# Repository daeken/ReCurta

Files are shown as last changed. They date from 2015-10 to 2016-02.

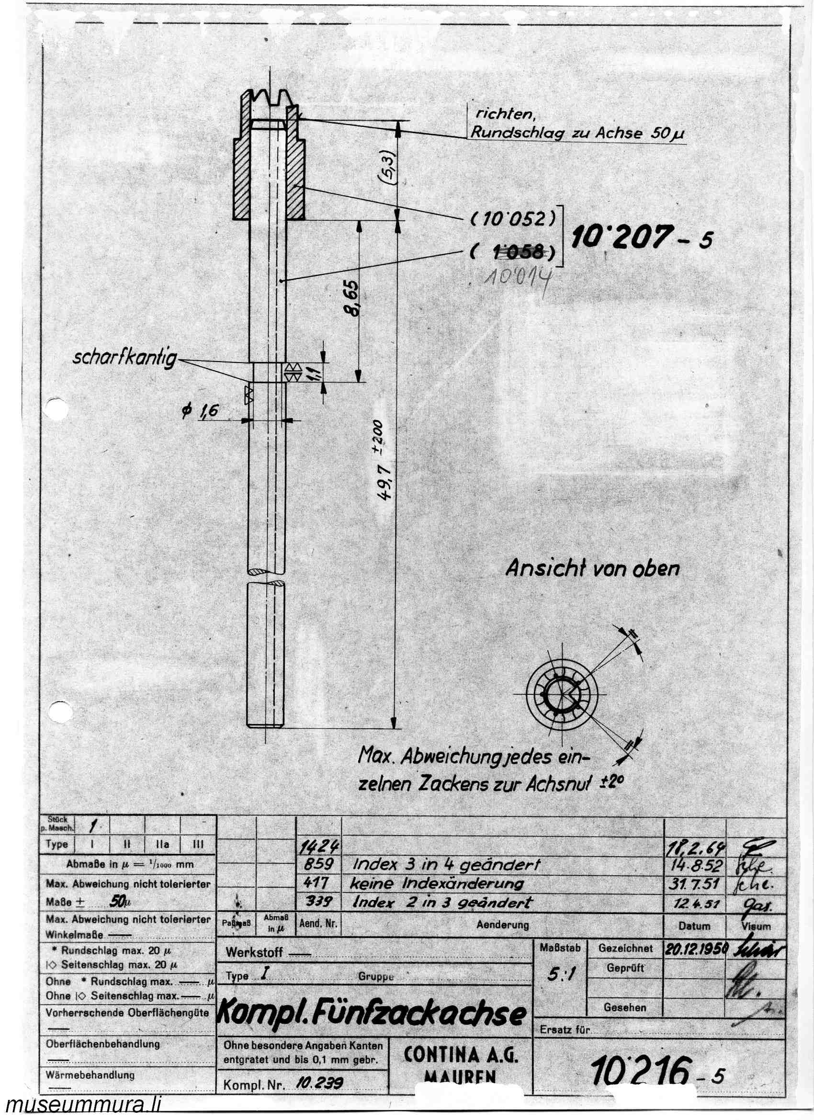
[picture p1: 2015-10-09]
app/curta_jpegs/assembly/Curta_1_10216.jpg

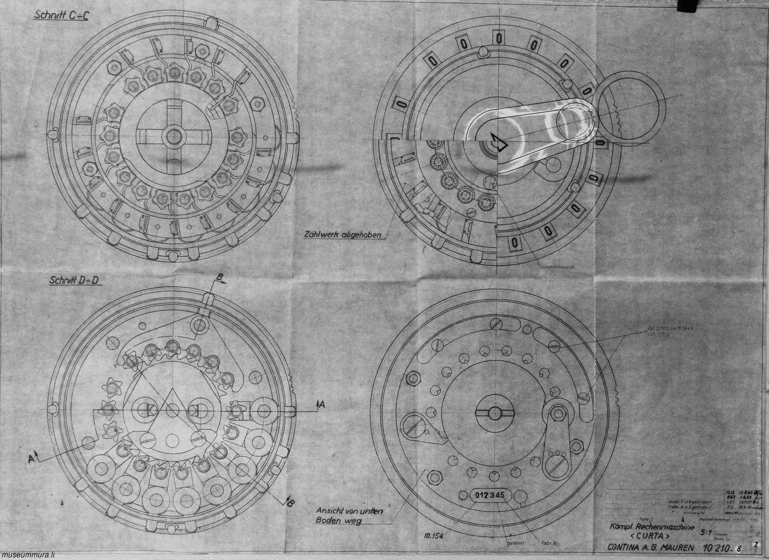
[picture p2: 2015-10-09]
app/curta_jpegs/assembly/Curta_1_10210_Z2.jpg

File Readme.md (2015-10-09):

Welcome to the ReCurta project!  Our goal is to translate the original Curta Type I engineering diagrams into English, redraw them using CAD software, and then use those diagrams to build the first Curta calculator since 1972.

Everything produced as part of this project is being released into the public domain.  Everyone should be able to inspect, visualize, or even build their own Curta calculator; it shouldn't be fated to forever be an expensive relic on eBay.

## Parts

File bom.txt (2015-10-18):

|| [[[10001]]] || Step drum body || 1 || M ||
|| [[[10002]]] || Housing top || 1 || M ||
|| [[[10003]]] || Main shaft || 1 || L ||
|| [[[10004]]] || Spider spring || 1 || C ||
|| [[[10005]]] || Ten carry lever for results || 10 || C ||
|| [[[10006]]] || Ten carry lever for turns || 5 || C ||
|| [[[10007]]] || Ten carry lever spring || 15 || Spring wind ||
|| [[[10008]]] || Numeral dial axles || 17 || L ||
|| [[[10009]]] || Tens bell body || 1 || L ||
|| [[[10010]]] || Step drum positioning tongue || 1 || C ||
|| [[[10011]]] || Upper main casting || 1 || M ||
|| [[[10012]]] || Crank handle || 1 || L ||
|| [[[10014]]] || Transmission shaft || 17 || L ||
|| [[[10015]]] || Shouldered screw || 1 || L ||
|| [[[10016]]] || Carriage shift positioning pin || 1 || L ||
|| [[[10018]]] || Ten carry lever bearing block || 15 || M ||
|| [[[10019]]] || Full carry pin || 7 || L ||
|| [[[10020]]] || Guide sleeve for transmission gears (aka 410345) || 1 || Lathe + Compression ||
|| [[[10021]]] || Half carry pin || 8 || M ||
|| [[[10022]]] || Crank handle pin || 1 || L ||
|| [[[10023]]] || Reversing lever spring || 1 || Buy ||
|| [[[10024]]] || Clearing plate plunger || 1 || L ||
|| [[[10025]]] || Main bearing sleeve body || 1 || L ||
|| [[[10026]]] || Carriage holding nut || 1 || L ||
|| [[[10027]]] || Carriage shift positioning pin || 1 || L ||
|| [[[10028]]] || Baseplate || 1 || M ||
|| [[[10029]]] || Number dial || 8 || L ||
|| [[[10030]]] || Clearing plate body || 1 || M ||
|| [[[10031]]] || Retaining ring || 1 || C ||
|| [[[10032]]] || Guide sleeve for transmission gears (aka 410346) || 1 || Lathe + Compression ||
|| [[[10033]]] || Flat spring || 1 || C ||
|| [[[10034]]] || Clearing Lever || 1 || M ||
|| [[[10035]]] || Retaining bushing for carriage pressure spring || 1 || L ||
|| [[[10036]]] || C-clip || 1 || M ||
|| [[[2118]]] || Retaining screw || 2 || L ||
|| [[[10038]]] || Count gear I (aka 410347) || 20 || C ||
|| [[[10039]]] || Clearing lever position plunger || 1 || L ||
|| [[[10040]]] || Carriage casting || 1 || M ||
|| [[[100402]]] || !IGNORE Carriage casting support IGNORE! || 1 ||  ||
|| [[[10041]]] || Ferrule (aka 410348) || 2 || L ||
|| [[[10042]]] || Transmission gear spacer (aka 410349) || 2 || L ||
|| [[[10043]]] || Numeral dial I || 4 || L ||
|| [[[10045]]] || Numeral dial II || 13 || L ||
|| [[[10046]]] || Decimal marker || 7 || L ||
|| [[[10047]]] || Decimal marker spring || 7 || Buy ||
|| [[[10048]]] || Cylindrical screws || 2 || L ||
|| [[[10049]]] || Lock gear (aka 410350) || 17 || C ||
|| [[[10050]]] || Carriage pressure spring || 1 || Buy ||
|| [[[10051]]] || Transmission gear spacer (aka 410351) || 15 || L ||
|| [[[10052]]] || Transmission gear || 17 || M ||
|| [[[10053]]] || Count gear II (aka 410352) || 15 || C ||
|| [[[10054]]] || Ferrule (aka 410353) || 15 || L ||
|| [[[10055]]] || Guide sleeve for transmission gears (aka 410354) || 15 || Lathe + Compression ||
|| [[[10056]]] || Guide sleeve for transmission gears || 1 || Lathe + Compression ||
|| [[[10057]]] || Setting knob || 8 || M ||
|| [[[10058]]] || NRP (Non-Return Pawl) spring || 1 || Buy ||
|| [[[10059]]] || NRP shouldered screw || 1 || L ||
|| [[[10061]]] || Setting Shaft || 8 || L ||
|| [[[10062]]] || Lower housing ring || 1 || L ||
|| [[[10064]]] || Support column || 3 || L ||
|| [[[10065]]] || Reversing lever axle || 1 || L ||
|| [[[10066]]] || Reversing handle || 1 || M ||
|| [[[10067]]] || Reversing plate || 1 || M ||
|| [[[10068]]] || Step drum positioning cam || 1 || L ||
|| [[[10069]]] || Taper pin for step drum || 1 || L ||
|| [[[10070]]] || Step drum positioning spring || 1 || M ||
|| [[[10071]]] || Locking ring || 1 || C ||
|| [[[10072]]] || Tens bell locking pin || 1 || L ||
|| [[[10073]]] || Setting knob spring || 8 || Buy ||
|| [[[10074]]] || Countersunk screws || 3 || L ||
|| [[[10075]]] || Guiding screw || 8 || L ||
|| [[[10076]]] || Drum plate 10 tooth || 1 || C ||
|| [[[10077]]] || Lower main casting || 1 || M ||
|| [[[10078]]] || Drum plate 1 tooth || 5 || C ||
|| [[[10079]]] || Drum plate 9 tooth || 2 || C ||
|| [[[10080]]] || Drum plate 2 tooth || 6 || C ||
|| [[[10081]]] || Drum plate 8 tooth || 2 || C ||
|| [[[10082]]] || Drum plate 3 tooth || 6 || C ||
|| [[[10083]]] || Drum plate 7 tooth || 2 || C ||
|| [[[10084]]] || Drum plate 4 tooth || 6 || C ||
|| [[[10085]]] || Collar || 1 || L ||
|| [[[10086]]] || Clearing plate spring || 1 || Buy ||
|| [[[10087]]] || Drum plate 6 tooth || 2 || C ||
|| [[[10088]]] || Carriage ring || 1 || L ||
|| [[[10089]]] || Carriage cage || 1 || M ||
|| [[[10090]]] || Drum plate 5 tooth || 5 || C ||
|| [[[10091]]] || Drum plate 1 tooth || 6 || C ||
|| [[[10093]]] || Clearing lever rivet || 1 || L ||
|| [[[10094]]] || Rivet washer || 1 || M ||
|| [[[10095]]] || Spring housing || 1 || L ||
|| [[[10096]]] || Drum plate 9 tooth || 1 || C ||
|| [[[10097]]] || Circlip for count gear || 9 || Cut or buy ||
|| [[[10098]]] || Small distance spring || 1 || M ||
|| [[[10099]]] || Clearing plate distance ring || 1 || M ||
|| [[[10100]]] || Turns counter carry increment || 1 || M ||
|| [[[10101]]] || Result counter carry increment || 1 || M ||
|| [[[10102]]] || Tens bell insert ring || 1 || M ||
|| [[[10103]]] || Tens bell insert ring || 2 || M ||
|| [[[10104]]] || Turns counter carry reset ring || 1 || M ||
|| [[[10105]]] || Turns counter lock ring || 1 || M ||
|| [[[10106]]] || Result counter carry reset ring || 1 || M ||
|| [[[10107]]] || Result counter lock ring || 1 || M ||
|| [[[10109]]] || Trunnion screw || 1 || L ||
|| [[[10110]]] || Transmission gear spacer (aka 410356) || 1 || L ||
|| [[[10111]]] || Zero positioning disc || 1 || L ||
|| [[[10112]]] || Zero positioning roller || 1 || L ||
|| [[[10113]]] || Non Return Pawl || 1 || M ||
|| [[[10114]]] || Zero positioning lever || 1 || M ||
|| [[[10115]]] || Zero positioning lever spring || 1 || Buy ||
|| [[[10116]]] || Screw for zero positioning lever || 1 || L ||
|| [[[2037]]] || Screw for zero positioning lever (looks to be for type II) || 1 || L ||
|| [[[10118]]] || Disc spring clip || 1 || Bend ||
|| [[[10119]]] || End plate || 1 || M ||
|| [[[10120]]] || Tens bell support plate || 1 || C ||
|| [[[10121]]] || Non Return Pawl bushing || 1 || L ||
|| [[[2074]]] || Nut || 2 || Buy ||
|| [[[10124]]] || Container tightening ring || 1 || Buy ||
|| [[[10125]]] || Barrel of zero positioning lever || 1 || L ||
|| [[[10126]]] || Decorative cover for top of capsule || 1 || M ||
|| [[[10129]]] || Carriage pressure ring || 1 || C ||
|| [[[10130]]] || Rubber cushion, large || 1 || Buy ||
|| [[[10131]]] || Rubber cushion, small || 1 || Buy ||
|| [[[10133]]] || C-clip || 1 || C ||
|| [[[10134]]] || Carriage turn stop pin || 1 || L ||
|| [[[10135]]] || Setting shaft bearing pin || 8 || L ||
|| [[[10136]]] || Setting shaft plates || 2 || C ||
|| [[[10137]]] || Retaining bushing, large || 1 || L ||
|| [[[10138]]] || Retaining bushing, small || 1 || L ||
|| [[[10140]]] || Guide sleeve for transmission gears (aka 410359) || 16 || Lathe + Compression ||
|| [[[10141]]] || Ferrule (aka 410360) || 17 || L ||
|| [[[10142]]] || Curved tooth racks || 2 || C ||
|| [[[10143]]] || Spacer for clearing plate || 1 || C ||
|| [[[10145]]] || Steel ball || 1 || Buy ||
|| [[[10147]]] || Main bearing sleeve bushing || 1 || L ||
|| [[[10148]]] || Cylindrical pin || 1 || L ||
|| [[[10149]]] || Cylindrical pin || 2 || L ||
|| [[[10150]]] || Cylindrical pin || 1 || L ||
|| [[[10152]]] || Split washer || 1 || Buy ||
|| [[[10153]]] || Shim washer || 1 || M ||
|| [[[10154]]] || Internal serial number plate || 1 || M ||
|| [[[10156]]] || Decorative plate for capsule || 1 || M ||
|| [[[10158]]] || Baseplate design || 1 || M ||
|| [[[10160]]] || Baseplate design II (Alternate drawing?) || 1 || M ||
|| [[[10161]]] || Retaining nut (Unused?) || 1 || L ||
|| [[[10162]]] || Washer || 1 || Buy ||
|| [[[410367]]] || Taper pin || 1 || L ||
|| [[[10203]]] || Number dial I || 4 ||  ||
|| [[[10204]]] || Number dial IIa || 7 ||  ||
|| [[[10205]]] || Number dial IIb || 4 ||  ||
|| [[[10206]]] || Tens bell || 1 ||  ||
|| [[[10207]]] || Transmission axle with gear || 1 ||  ||
|| [[[10208]]] || Transmission shaft || 12 ||  ||
|| [[[10209]]] || Transmission shaft || 1 ||  ||
|| [[[10210]]] || Main assembly || 1 ||  ||
|| [[[10211]]] || Reversing handle assembly || 1 ||  ||
|| [[[10212]]] || Complete setting shaft || 1 ||  ||
|| [[[10213]]] || Step drum || 1 ||  ||
|| [[[10214]]] || Main shaft || 1 ||  ||
|| [[[10215]]] || Lower housing || 1 ||  ||
|| [[[10216]]] || Transmission shaft || 1 ||  ||
|| [[[10218]]] || Triple count gear assembly || 1 ||  ||
|| [[[10219]]] || Double count gear assembly || 1 ||  ||
|| [[[10220]]] || Tens gear/locking assembly || 15 ||  ||
|| [[[10221]]] || Non-carry locking assembly || 1 ||  ||
|| [[[10222]]] || Non-carry locking assembly (Long) || 1 ||  ||
|| [[[10223]]] || Main shaft || 1 ||  ||
|| [[[10224]]] || Non return pawl assembly || 1 ||  ||
|| [[[10225]]] || Zero positioner lever || 1 ||  ||
|| [[[10226]]] || Carriage casting || 1 ||  ||
|| [[[10227]]] || Upper main body with tens bell || 1 ||  ||
|| [[[10228]]] || Capsule assembly || 1 ||  ||
|| [[[10229]]] || Main bearing sleeve || 1 ||  ||
|| [[[10230]]] || Single count gear assembly || 15 ||  ||
|| [[[10231]]] || Lower main casting assembly || 1 ||  ||
|| [[[10232]]] || Assembly step I || 1 ||  ||
|| [[[10233]]] || Assembly step II || 1 ||  ||
|| [[[10234]]] || Assembly step III || 1 ||  ||
|| [[[10236]]] || Transmission shaft, IV || 12 ||  ||
|| [[[10237]]] || Transmission shaft, I || 1 ||  ||
|| [[[10238]]] || Transmission shaft, II || 3 ||  ||
|| [[[10239]]] || Transmission shaft, III || 1 ||  ||
|| [[[10240]]] || Setting handle complete assembly || 8 ||  ||
|| [[[10241]]] || Reversing switch complete assembly || 1 ||  ||
|| [[[10242]]] || Plastic crank || 1 ||  ||
|| [[[10243]]] || Carriage assembly step I || 1 ||  ||
|| [[[10244]]] || Clearing plate || 1 ||  ||
|| [[[10245]]] || Crank handle || 1 ||  ||
|| [[[10246]]] || Zero positioner || 1 ||  ||
|| [[[10247]]] || Clearing plate with pressed segments || 1 ||  ||
|| [[[10248]]] || Upper main body with pins || 1 ||  ||
|| [[[10249]]] || Baseplate assembly || 1 ||  ||
|| [[[10250]]] || Setting handle with guide screw || 8 ||  ||

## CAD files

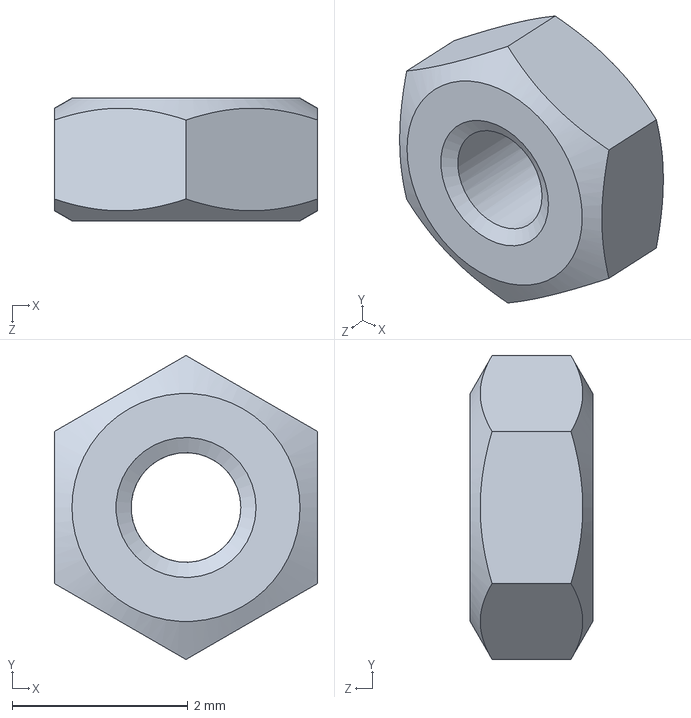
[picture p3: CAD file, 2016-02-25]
Solidworks Drawings/2074.sldprt
3.00 x 3.46 x 1.40 mm

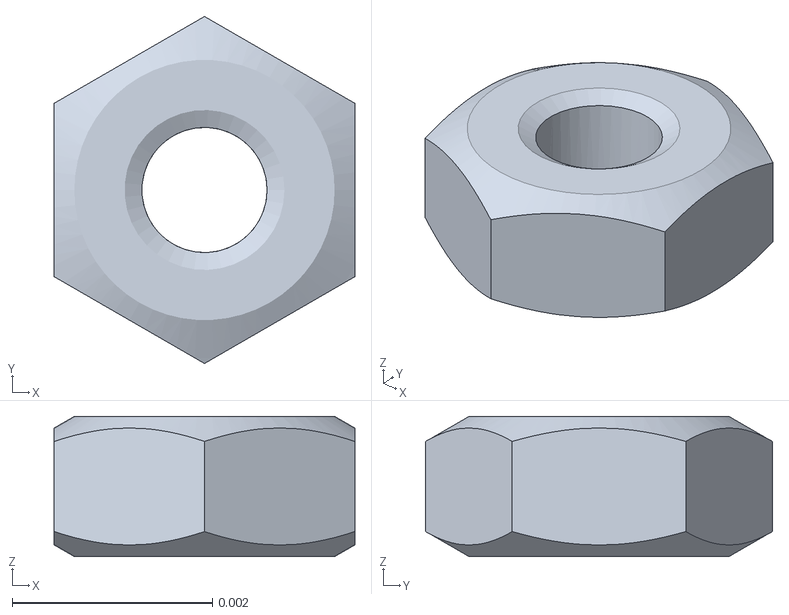
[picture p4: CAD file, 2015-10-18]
STL Models/2074.stl
0.003 x 0.00346 x 0.0014

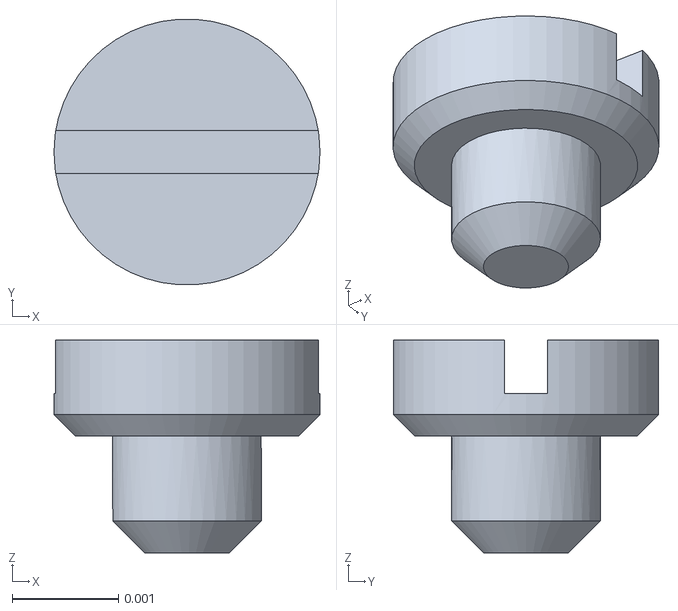
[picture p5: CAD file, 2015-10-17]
STL Models/2118.stl
0.0025 x 0.0025 x 0.002

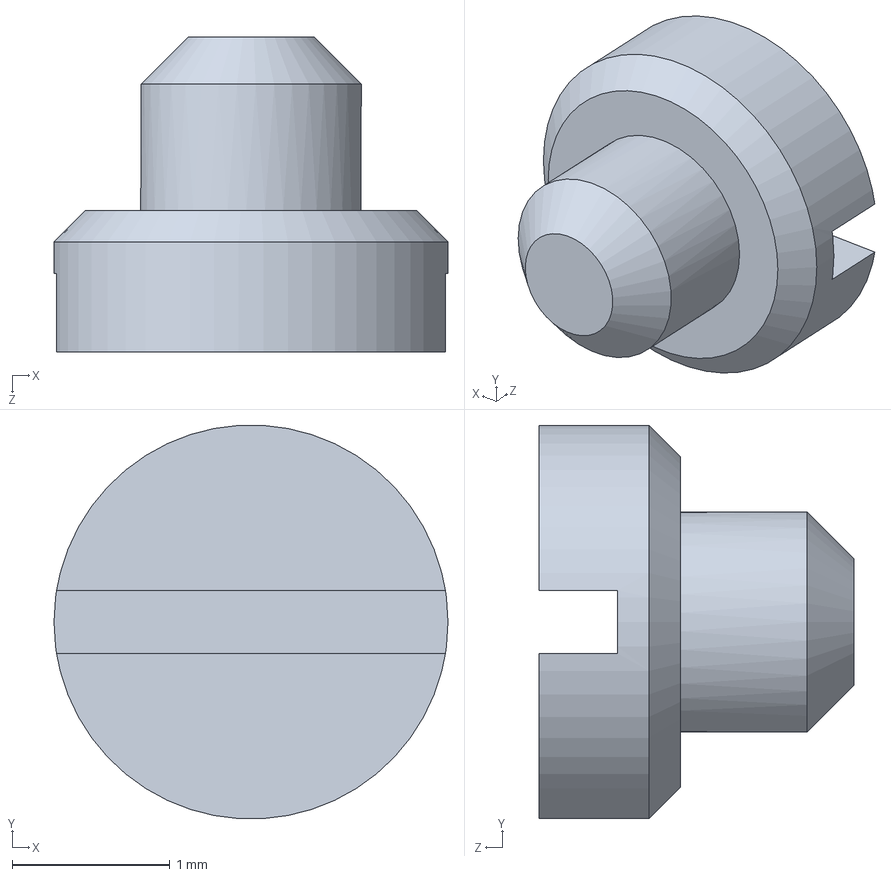
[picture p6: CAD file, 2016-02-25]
Solidworks Drawings/2118.sldprt
2.50 x 2.50 x 2.00 mm

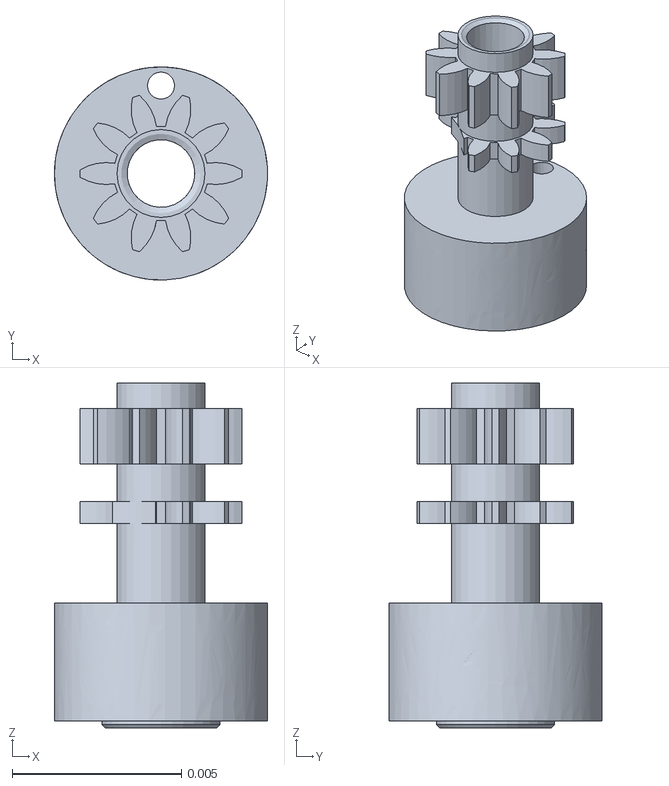
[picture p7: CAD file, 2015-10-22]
STL Models/10043.stl
0.0063 x 0.0063 x 0.0102

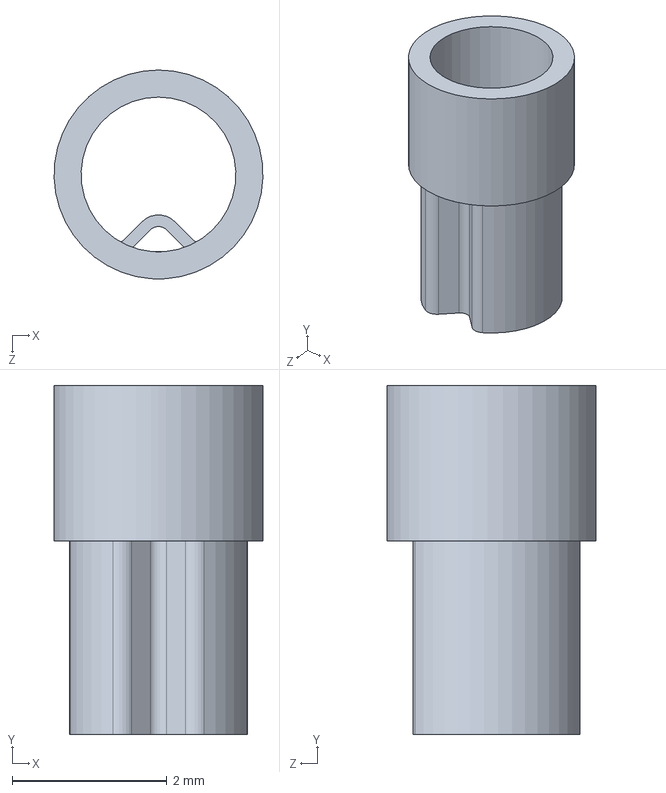
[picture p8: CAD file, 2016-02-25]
Solidworks Drawings/10140.sldprt
2.70 x 4.51 x 2.70 mm

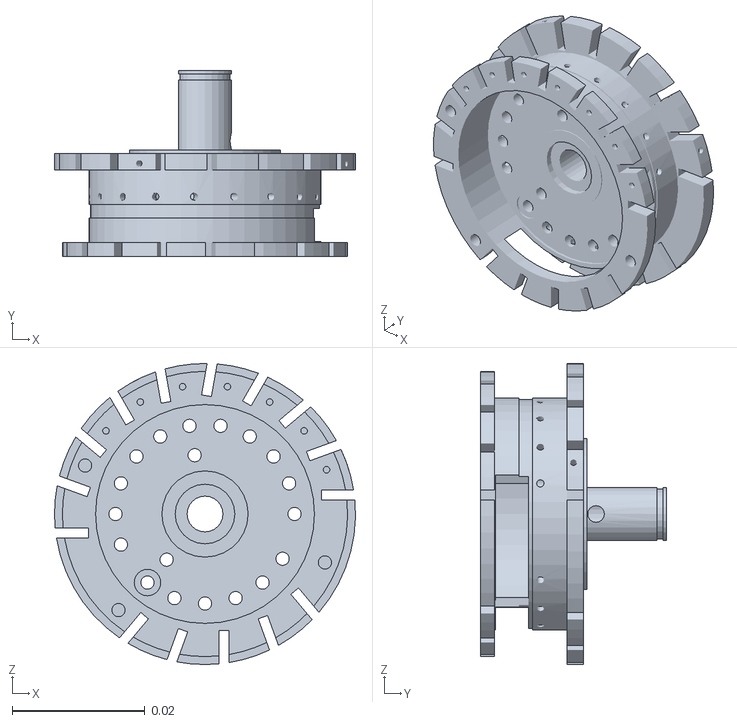
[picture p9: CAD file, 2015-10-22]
STL Models/10011.stl
0.0454 x 0.028 x 0.0454

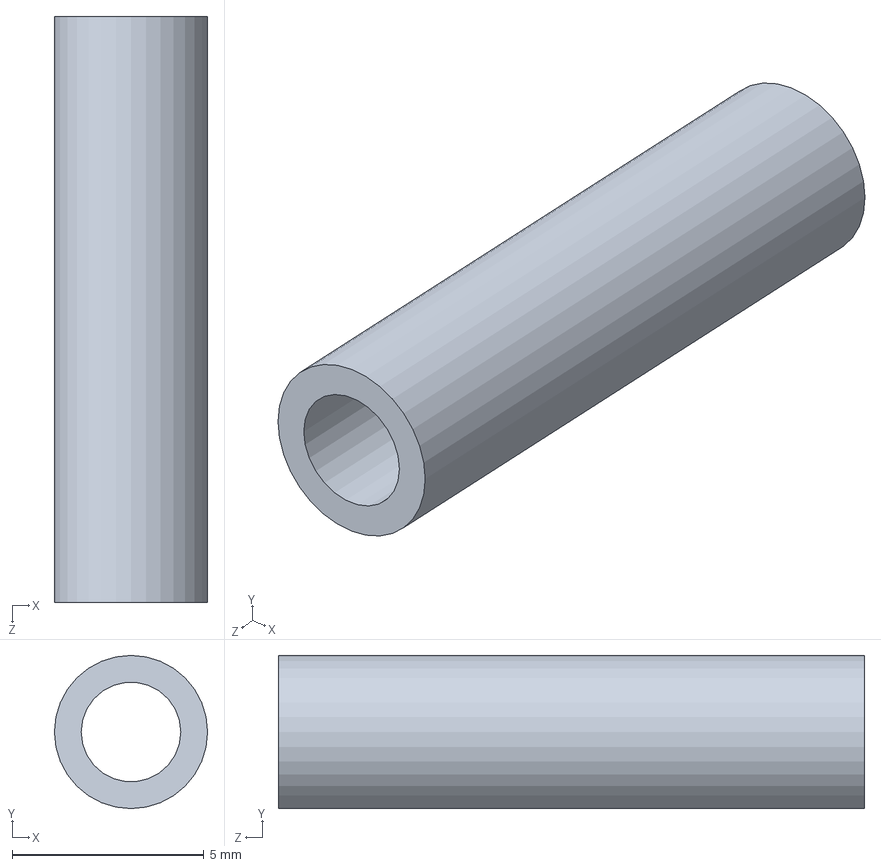
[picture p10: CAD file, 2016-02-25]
Solidworks Drawings/10137.sldprt
4.00 x 4.00 x 15.3 mm

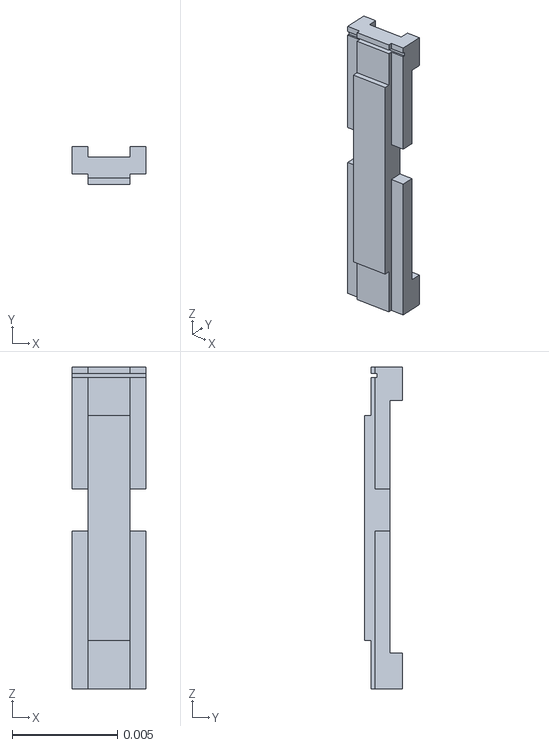
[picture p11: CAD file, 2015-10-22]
STL Models/10018.stl
0.0035 x 0.0018 x 0.0153

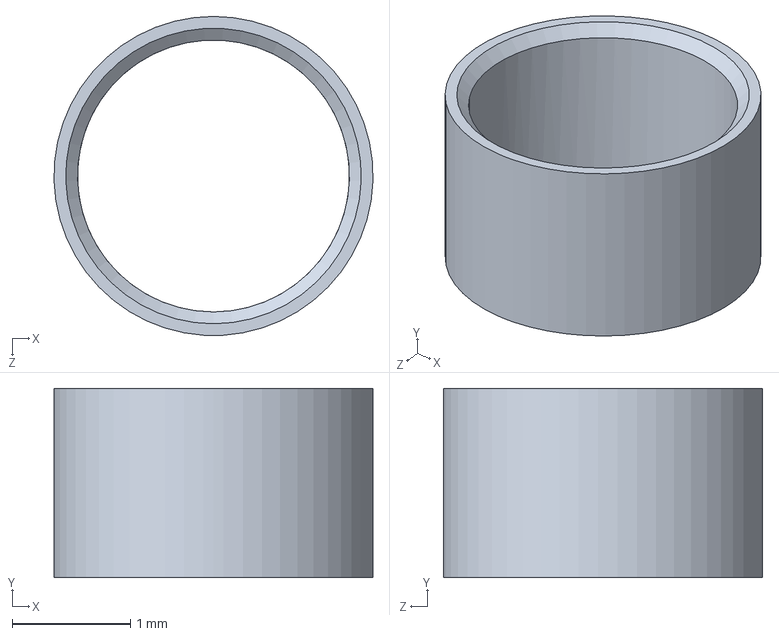
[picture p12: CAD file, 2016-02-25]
Solidworks Drawings/10141.sldprt
2.70 x 1.60 x 2.70 mm

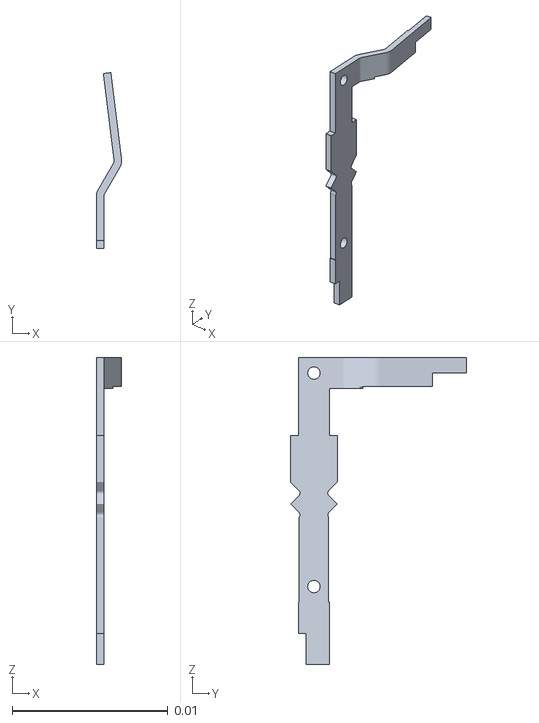
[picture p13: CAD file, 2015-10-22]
STL Models/10005.stl
0.00163 x 0.0113 x 0.0197

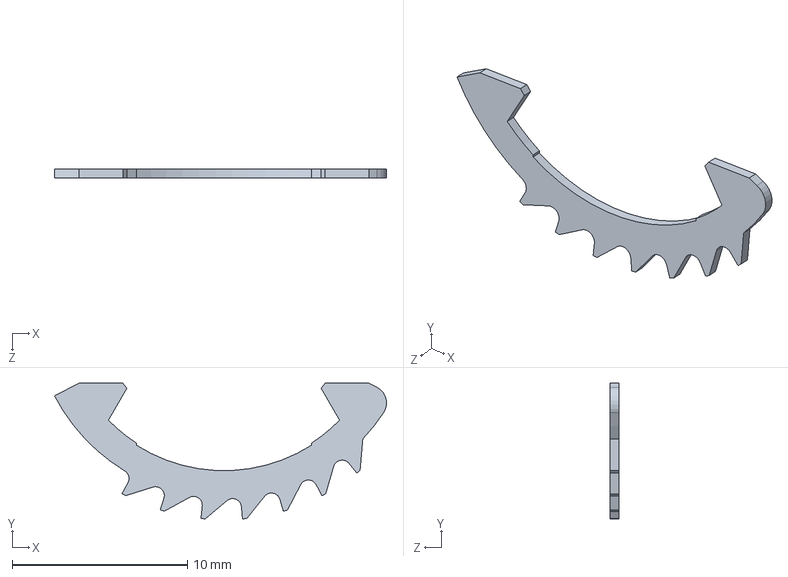
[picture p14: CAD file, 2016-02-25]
Solidworks Drawings/10083.sldprt
18.9 x 7.75 x 0.5 mm

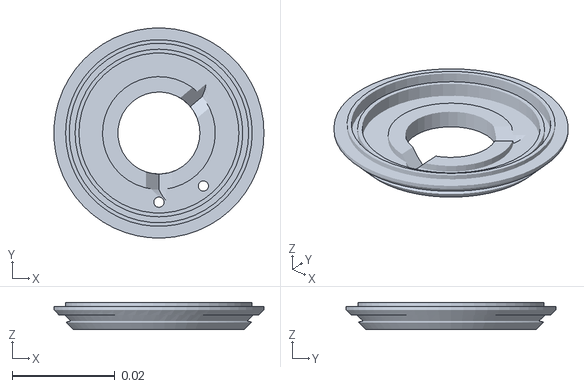
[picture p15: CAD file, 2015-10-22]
STL Models/10030.stl
0.041 x 0.041 x 0.0053

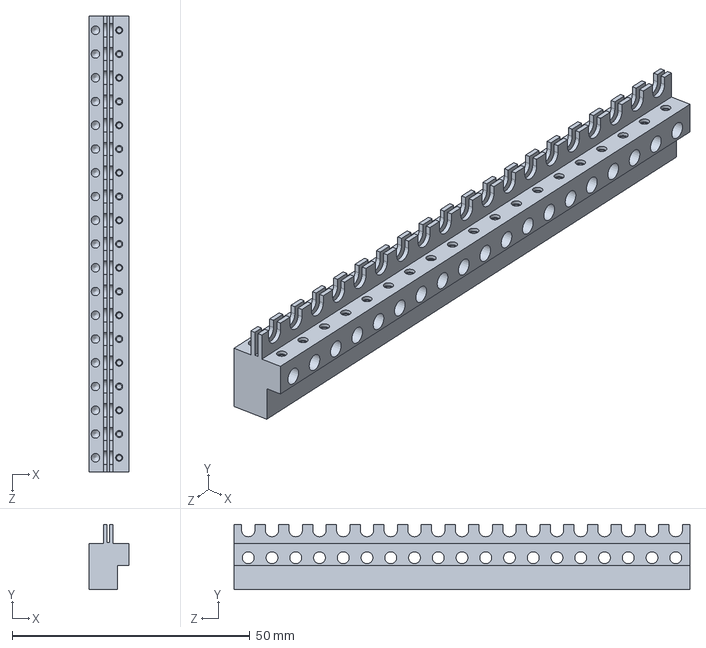
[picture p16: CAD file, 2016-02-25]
Solidworks Drawings/10057.sldprt
8.50 x 13.7 x 96.0 mm

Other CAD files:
STL Models/10101.stl
Solidworks Drawings/10112.sldprt
STL Models/10006.stl
Solidworks Drawings/10002.sldprt
STL Models/10001.stl
STL Models/10003.stl
STL Models/10004.stl
STL Models/10007.stl
STL Models/10008.stl
STL Models/10009.stl
STL Models/10010.stl
STL Models/10012.stl
STL Models/10014.stl
STL Models/10015.stl
STL Models/10019.stl
STL Models/10020.stl
STL Models/10021.stl
STL Models/10022.stl
STL Models/10023.stl
STL Models/10024.stl
STL Models/10025.stl
STL Models/10026.stl
STL Models/10028.stl
STL Models/10029.stl
STL Models/10031.stl
STL Models/10032.stl
STL Models/10033.stl
STL Models/10034.stl
STL Models/10035.stl
STL Models/10036.stl
STL Models/10038.stl
STL Models/10039.stl
STL Models/10040.stl
STL Models/10041.stl
STL Models/10042.stl
STL Models/10045.stl
STL Models/10046.stl
STL Models/10047.stl
STL Models/10048.stl
STL Models/10049.stl
STL Models/10050.stl
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

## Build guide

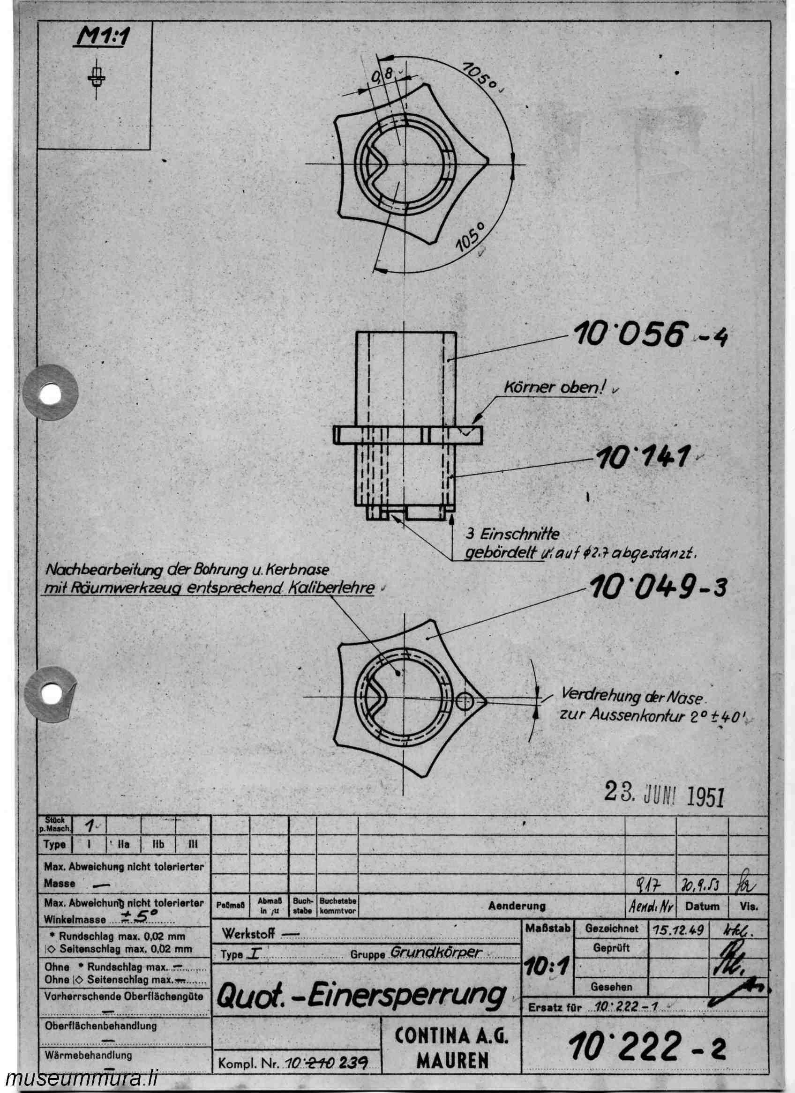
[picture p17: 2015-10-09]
app/curta_jpegs/assembly/Curta_1_10222.jpg

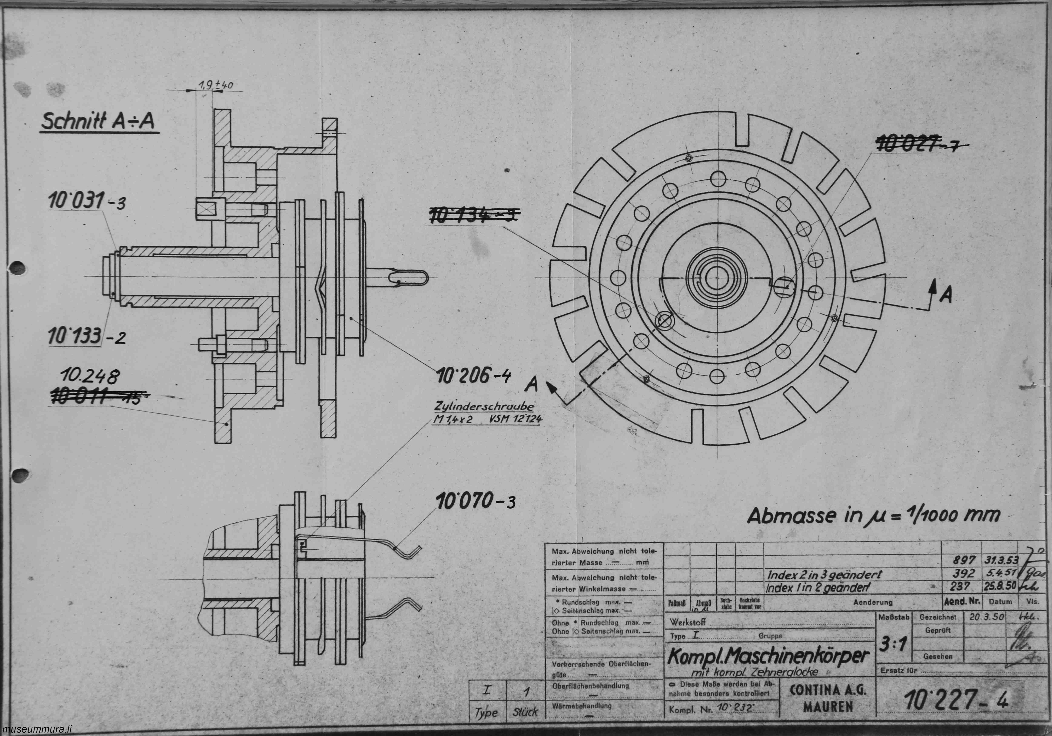
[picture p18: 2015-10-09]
app/curta_jpegs/assembly/Curta_1_10227.jpg

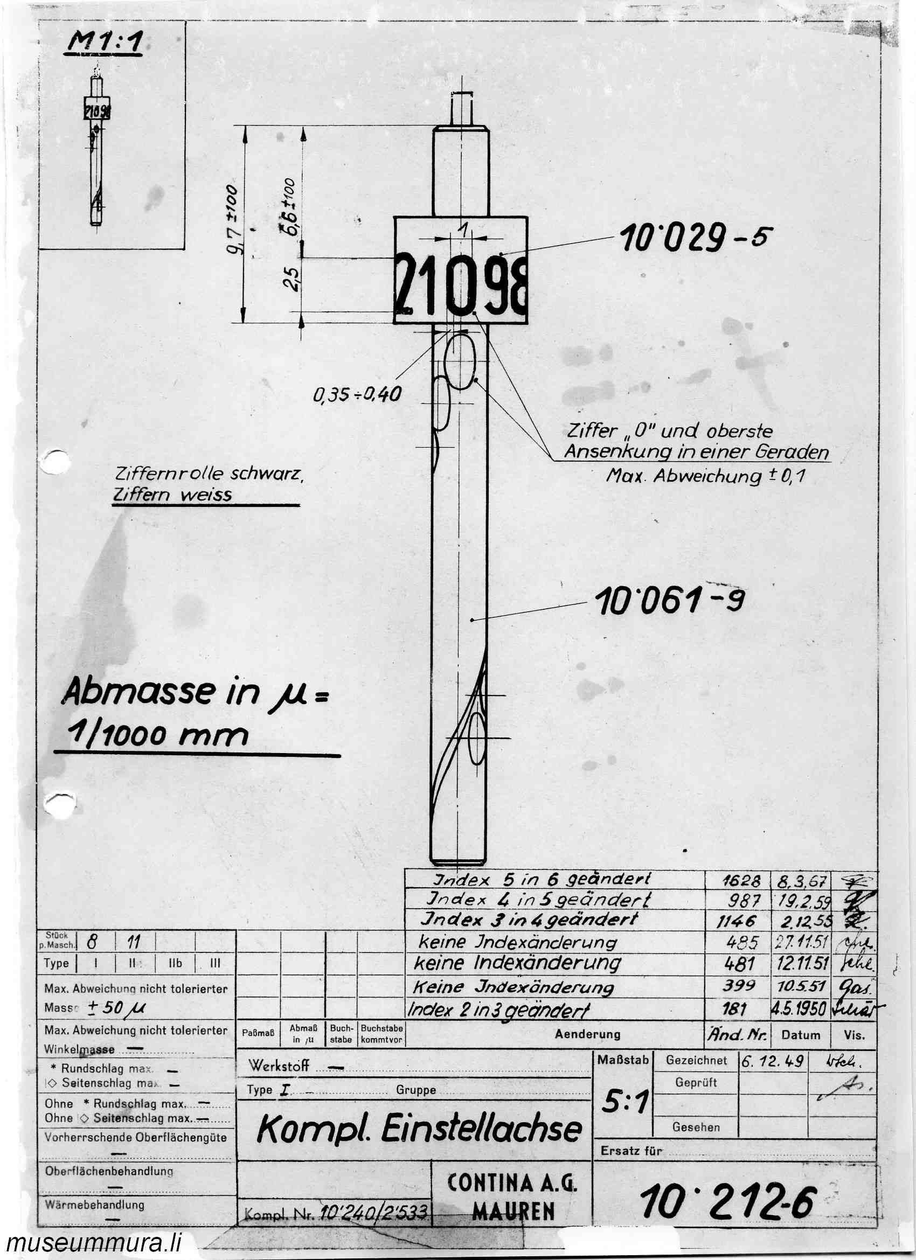
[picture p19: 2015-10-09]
app/curta_jpegs/assembly/Curta_1_10212.jpg

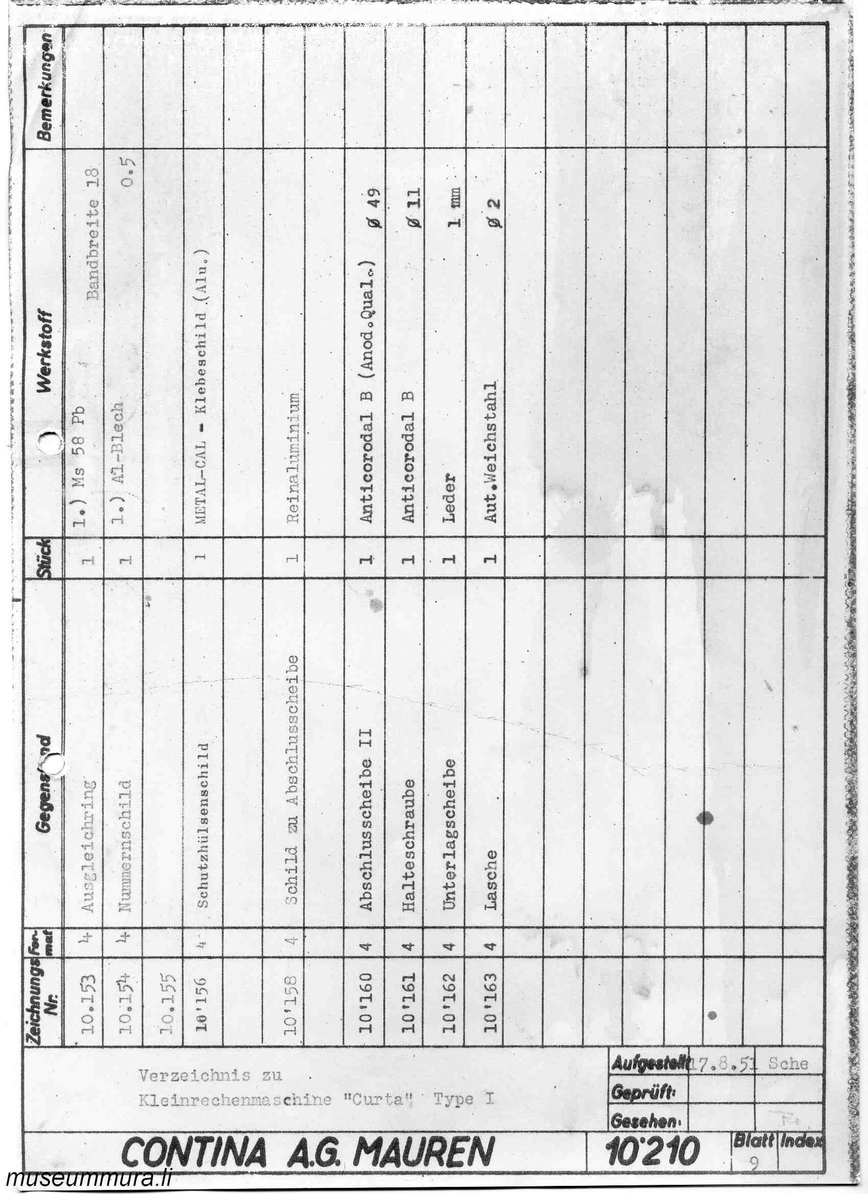
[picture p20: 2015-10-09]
app/curta_jpegs/assembly/Curta_1_10210_9.jpg

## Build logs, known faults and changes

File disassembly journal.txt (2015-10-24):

Top already off, case off.

Setting shaft plate 1 removed -- 10136
clockwise-most setting shaft bearing and shaft removed -- 10135, 3.38mm length (real 3.377mm).  marked #1
second bearing removed.  3.41mm length, 3.404mm real. marked #2
third removed.  3.44mm intended length, 3.404mm real. marked #3
fourth removed.  3.47mm intended length, 3.405mm real. marked #4
second shaft plate removed
fifth bearing removed.  3.50mm intended length, 3.414mm real. marked #5
sixth bearing removed.  3.53mm intended length, 3.407mm real. marked #6
seventh bearing removed.  3.56mm intended length, 3.386mm real! marked #7.  2.288mm diameter (2.3mm expected)
eighth bearing removed.  3.59mm intended length, 3.403mm real. marked #8.

looking at the curta with the shaft (where the handle would be) pointing away and the reversing lever to the left, i'm taking out the first setting position carry assembly.
using purple screwdriver, removed screw (M1.4x5, VSM 12124).  lifted assembly straight out.
first removed carry lever (10005) from bearing block (10018), then slipped spring (10007) off bearing block.
second carry assembly removed with same procedure.
NOTE: lever fits into bearing block with short end of lever barely sticking out!

while holding carry assembly, hold it with the flat face of lever (and spring ends) pointing up.  lift lever out of place, then push tines of spring down to release it securely.  third through tenth removed and disassembled using this procedure, safely.

the same procedure was followed for the tens carry assemblies for turns.  these use lever 10006 -- NOT 10005.

removed hex nut from reversing lever assembly.  pushed shaft down until slotted section of shaft appeared, then pulled the assembly straight out, through the slot in the lower casting.  removed lower bearing from shaft (unknown part number.  15.282mm long, 4mm OD, 2.42mm ID), and removed upper bearing from shaft (unknown part number.  5.011mm long, 4mm OD, 2.4mm ID). all parts placed into labeled container

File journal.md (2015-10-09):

10/08/15
=======

Decided to start keeping a development journal, to properly document this project once it's completed.

Status
------

- All drawings for the Type I are converted from the museummura.li sources
- Each part has been named in English and cross-referenced with the others
	- Every part referenced from each manufacturing diagram is indexed
- Out of 146 part diagrams, all but 38 are fully translated; those remaining 38 have 57 individual German phrases that need to be translated
	- These have all been automatically rewritten into English
- All of this is published on Github

Next Steps
----------

- Complete translations of all of the diagrams
	- Perform final review
- Add translated diagrams to the wiki
- Find and hire CAD designers to begin translation of diagrams to modern formats
- Determine all of the different manufacturing processes that need to be used
- Calculate approximate prices for replicas

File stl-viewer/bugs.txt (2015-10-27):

10021 missing flat face
10039 missing cap
10059 missing half its top
10068 missing top
10072 missing top
10074 missing part of top
10075 missing part of top
10076 missing part of one tooth
10078 empty?
10080 empty?
10082 empty?
10083 empty?
10084 empty?

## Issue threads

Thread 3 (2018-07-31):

Assembly

neilpanchal, 2018-07-31:
Is there a final assembly file, preferably in Solidworks? I've watched and looked at several documents including the service manual, but there is no way I can figure out how to assemble the parts in this repository into a final Solidworks assembly.

tswaugh, 2018-07-31:
There's an assembly video out there for the 3x scale 3D printed Curta: https://www.youtube.com/watch?v=zh2Z11miQ0w

neilpanchal, 2018-08-02:
@tswaugh No, I didn't mean physical assembly. I meant assembly of CAD parts. In Solidworks, you can build an assembly (.sldasm) from individual parts (.sldprt). It is just not putting parts together in CAD, but putting the right axial rotation, translation, angular constraints including spring tension.

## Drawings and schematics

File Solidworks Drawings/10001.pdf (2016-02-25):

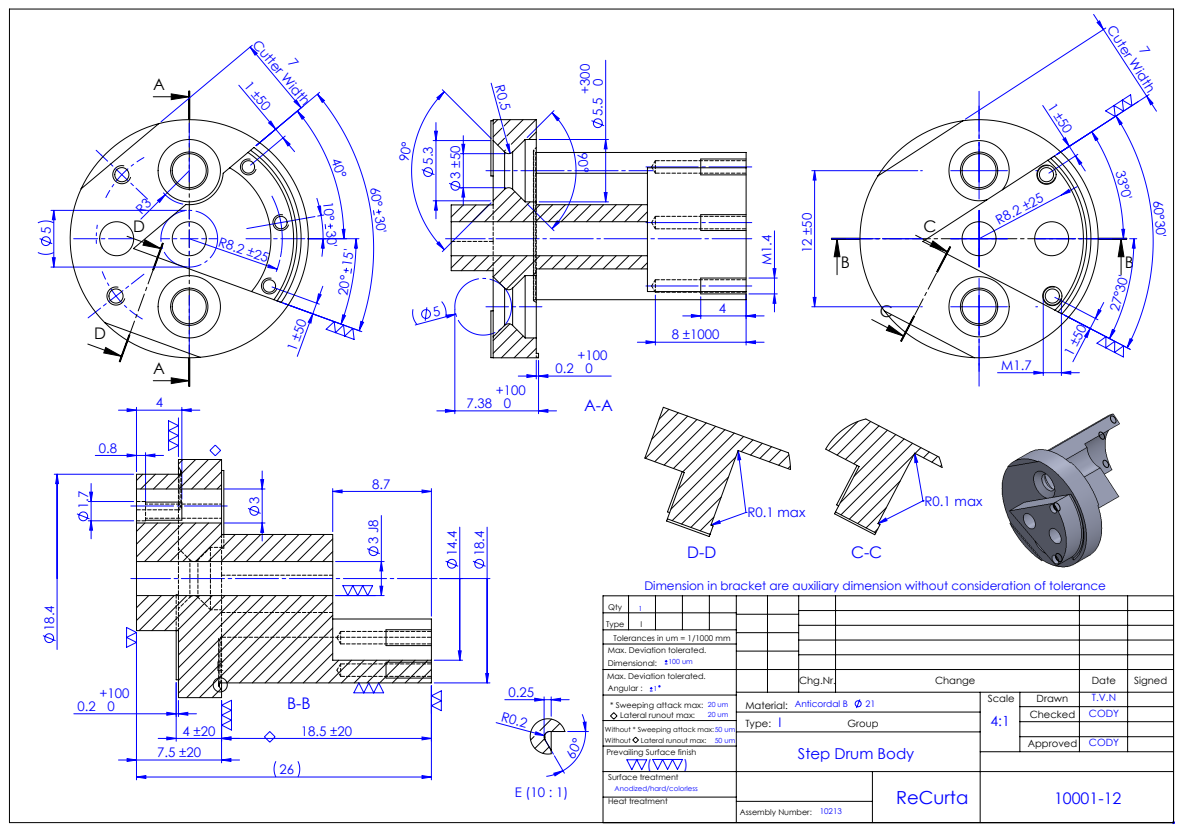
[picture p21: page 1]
Cutter Width; Cuter Width; R0.1 max; Anticordal B; Assembly Number:

Dimension in bracket are auxiliary dimension without consideration of tolerance

Qty | 1
Type | I

Tolerances in um = 1/1000 mm
Max. Deviation tolerated.
Dimensional:
Angular :
* Sweeping attack max:
Lateral runout max:
Without * Sweeping attack max:
Without Lateral runout max:
Prevailing Surface finish

Step Drum Body

Surface treatment
Anodized/hard/colorless
Heat treatment

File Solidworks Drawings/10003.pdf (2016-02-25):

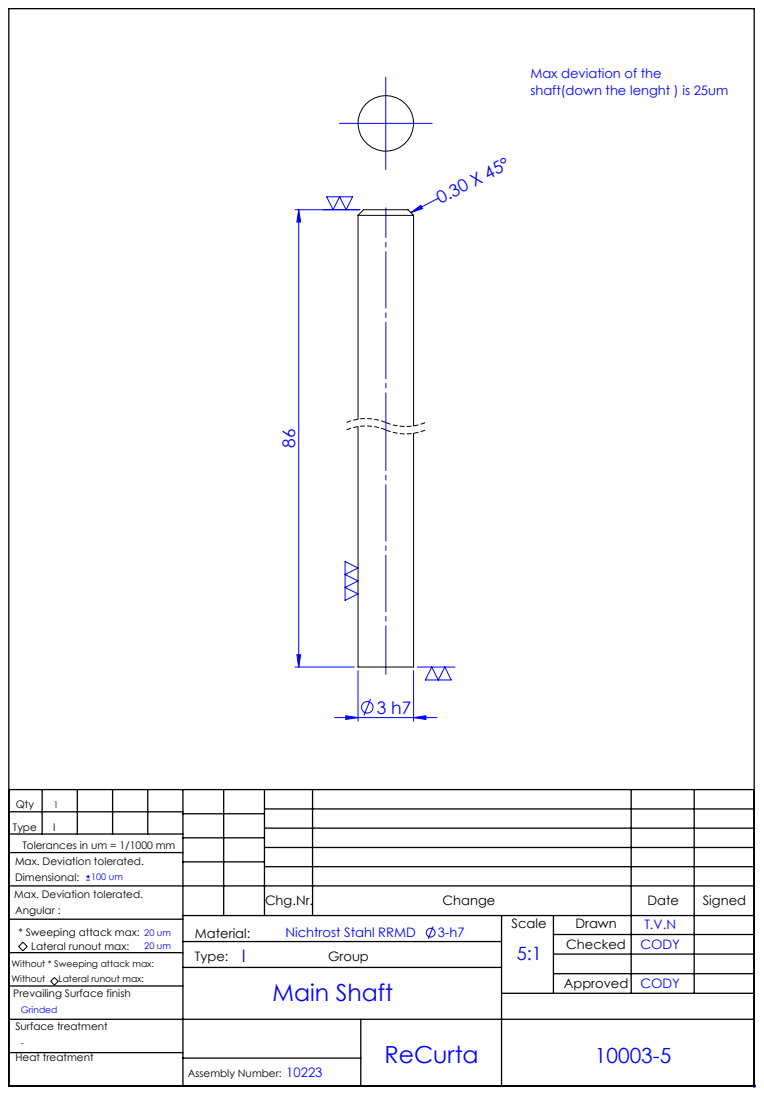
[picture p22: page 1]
Main Shaft; Assembly Number:

Max deviation of the
shaft(down the lenght ) is 25um

Qty | 1
Type | I

Tolerances in um = 1/1000 mm
Max. Deviation tolerated.
Dimensional:

Max. Deviation tolerated. Angular : | | | Chg.Nr. | Change | Date | Signed

Nichtrost Stahl RRMD 3-h7 | Scale 5:1 | Drawn Material: | T.V.N

* Sweeping attack max:
Lateral runout max:
Without * Sweeping attack max:
Without Lateral runout max:
Prevailing Surface finish
Grinded
Surface treatment
Heat treatment

Checked | CODY

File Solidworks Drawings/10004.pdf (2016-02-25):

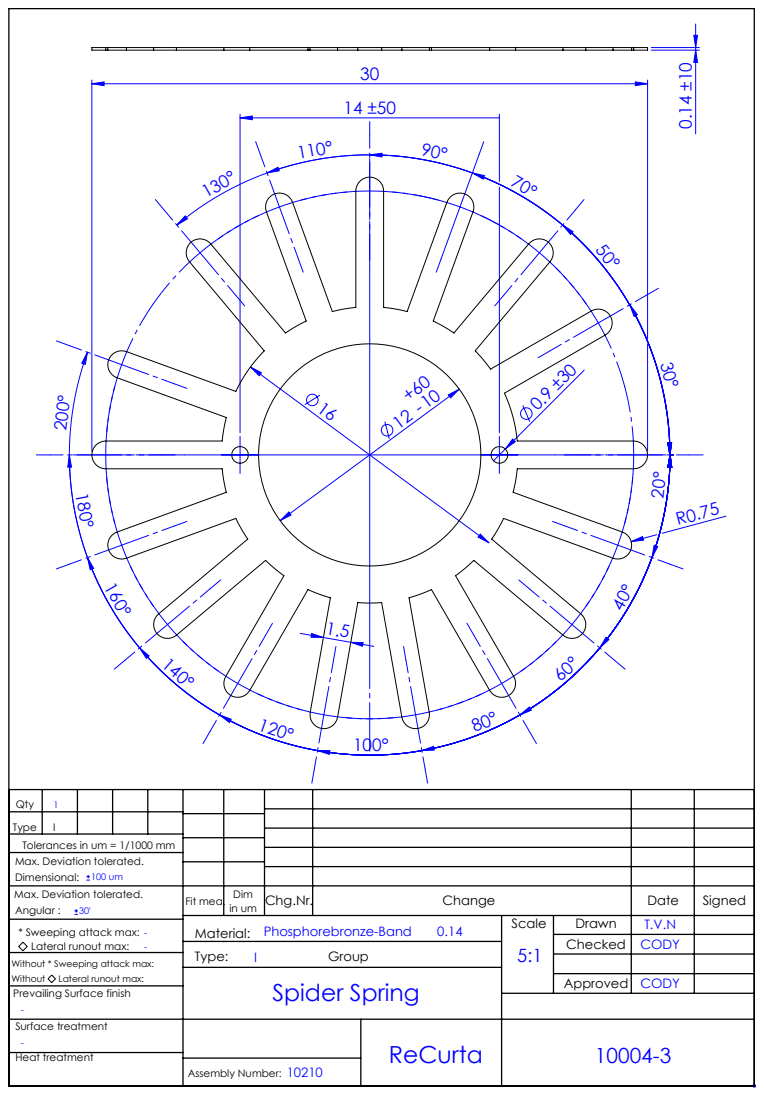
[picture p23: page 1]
Spider Spring; Assembly Number:

Qty | 1
Type | I

Tolerances in um = 1/1000 mm
Max. Deviation tolerated.
Dimensional:

Max. Deviation tolerated. Angular : 30' | Fit mea. Dim | in um | Chg.Nr. | Change | Date | Signed

Phosphorebronze-Band 0.14 | Scale 5:1 | Drawn Material: | T.V.N

* Sweeping attack max:
Lateral runout max:
Without * Sweeping attack max:
Without Lateral runout max:
Prevailing Surface finish
Surface treatment
Heat treatment

Checked | CODY

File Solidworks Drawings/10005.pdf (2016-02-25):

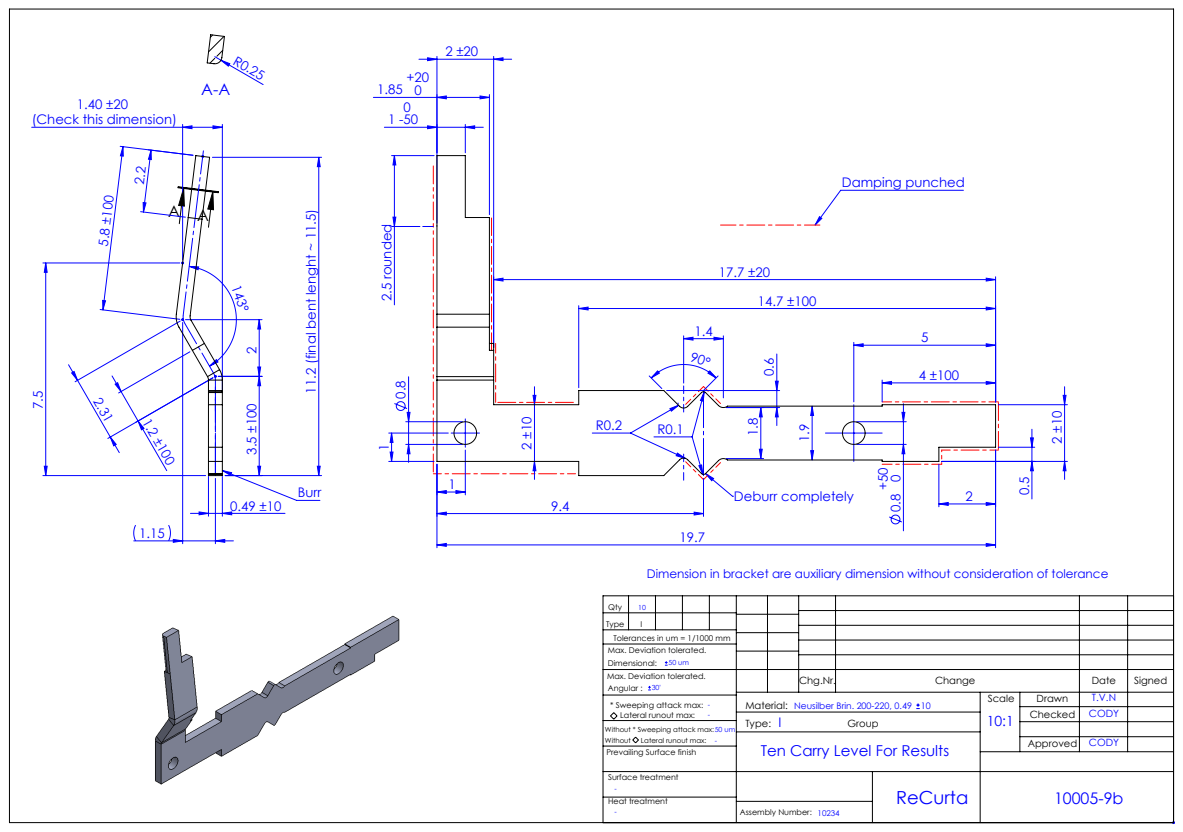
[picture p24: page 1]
2.5 rounded; Damping punched; Deburr completely; Neusilber Brin. 200-220, 0.49 10; Surface treatment; Assembly Number:

(Check this dimension)

11.2 (final bent lenght ~ 11.5)

Dimension in bracket are auxiliary dimension without consideration of tolerance

Qty | 10
Type | I

Tolerances in um = 1/1000 mm
Max. Deviation tolerated.
Dimensional:
Angular :
* Sweeping attack max:
Lateral runout max:
Without * Sweeping attack max:
Without Lateral runout max:
Prevailing Surface finish
Heat treatment

Ten Carry Level For Results

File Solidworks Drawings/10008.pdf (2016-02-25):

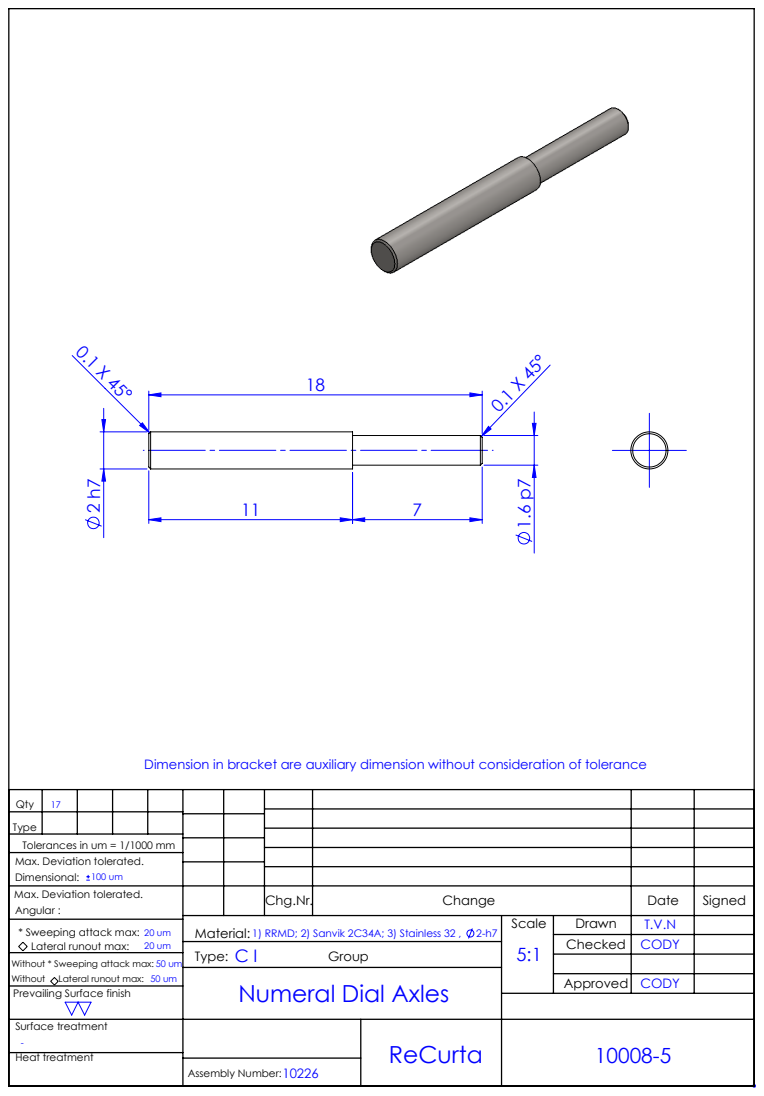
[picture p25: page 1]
Assembly Number:; Heat treatment; Surface treatment

Dimension in bracket are auxiliary dimension without consideration of tolerance

Qty | 17
Type

Tolerances in um = 1/1000 mm
Max. Deviation tolerated.
Dimensional:

Max. Deviation tolerated. Angular : | | | Chg.Nr. | Change | Date | Signed

1) RRMD; 2) Sanvik 2C34A; 3) Stainless 32 , 2-h7 | Scale 5:1 | Drawn Material: | T.V.N

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

Numeral Dial Axles

Checked | CODY

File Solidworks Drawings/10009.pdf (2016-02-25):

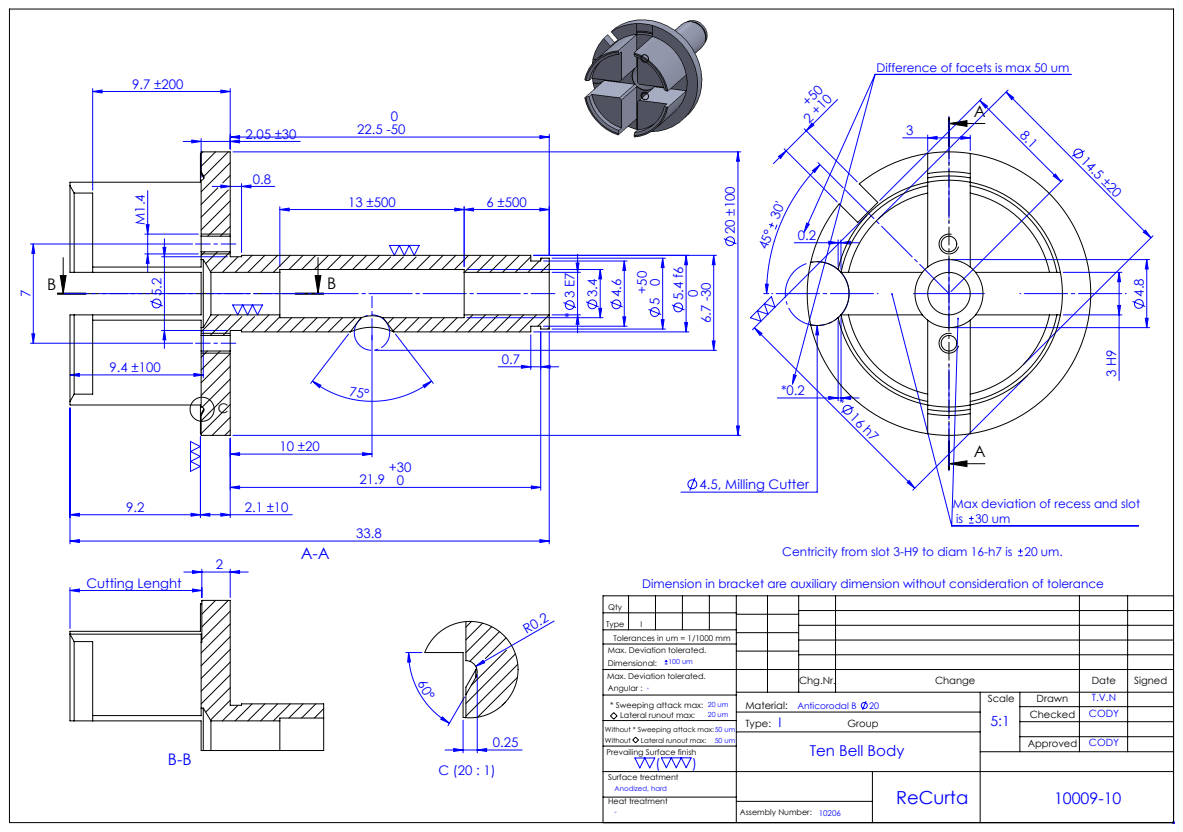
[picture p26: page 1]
4.5, Milling Cutter; Cutting Lenght; Anodized, hard; Anticorodal B 20; Centricity from slot 3-H9 to diam 16-h7 is; Surface treatment; Heat treatment; Assembly Number:

Difference of facets is max 50 um

Max deviation of recess and slot

Dimension in bracket are auxiliary dimension without consideration of tolerance

Qty
Type | I

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

Ten Bell Body

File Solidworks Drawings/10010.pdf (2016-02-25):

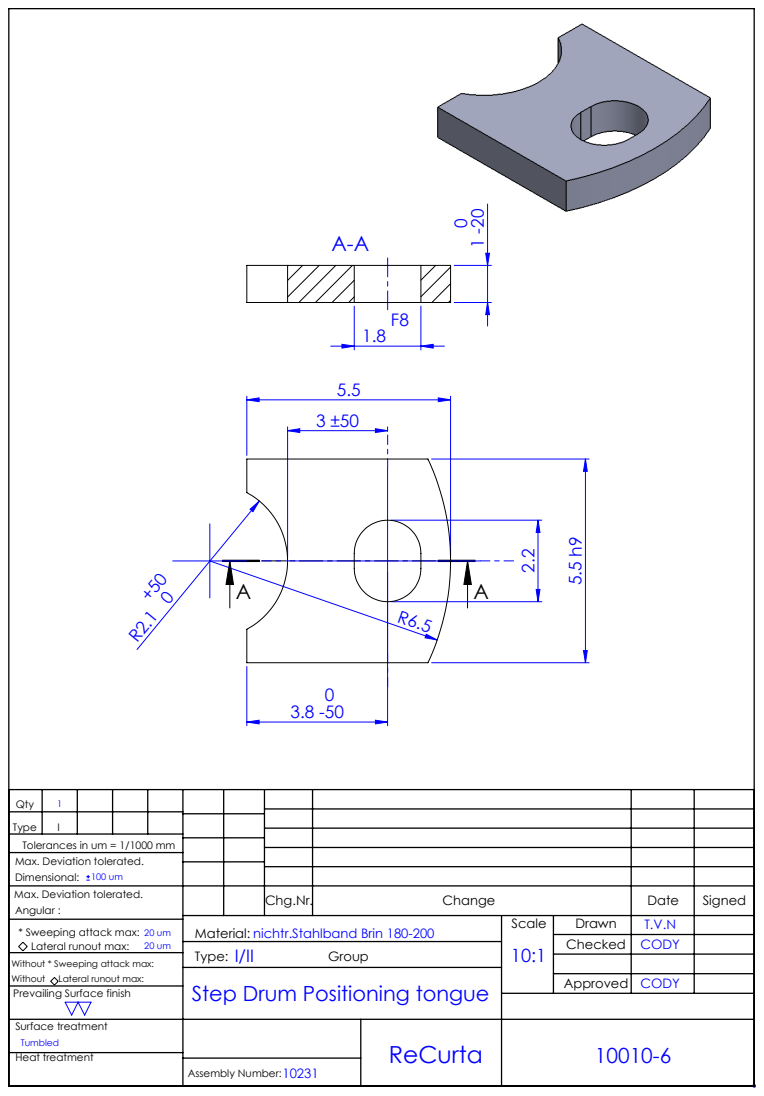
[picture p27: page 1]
Assembly Number:; Heat treatment; Surface treatment

Qty | 1
Type | I

Tolerances in um = 1/1000 mm
Max. Deviation tolerated.
Dimensional:

Max. Deviation tolerated. Angular : | | | Chg.Nr. | Change | Date | Signed

nichtr.Stahlband Brin 180-200 | Scale 10:1 | Drawn Material: | T.V.N

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

Step Drum Positioning tongue

Checked | CODY

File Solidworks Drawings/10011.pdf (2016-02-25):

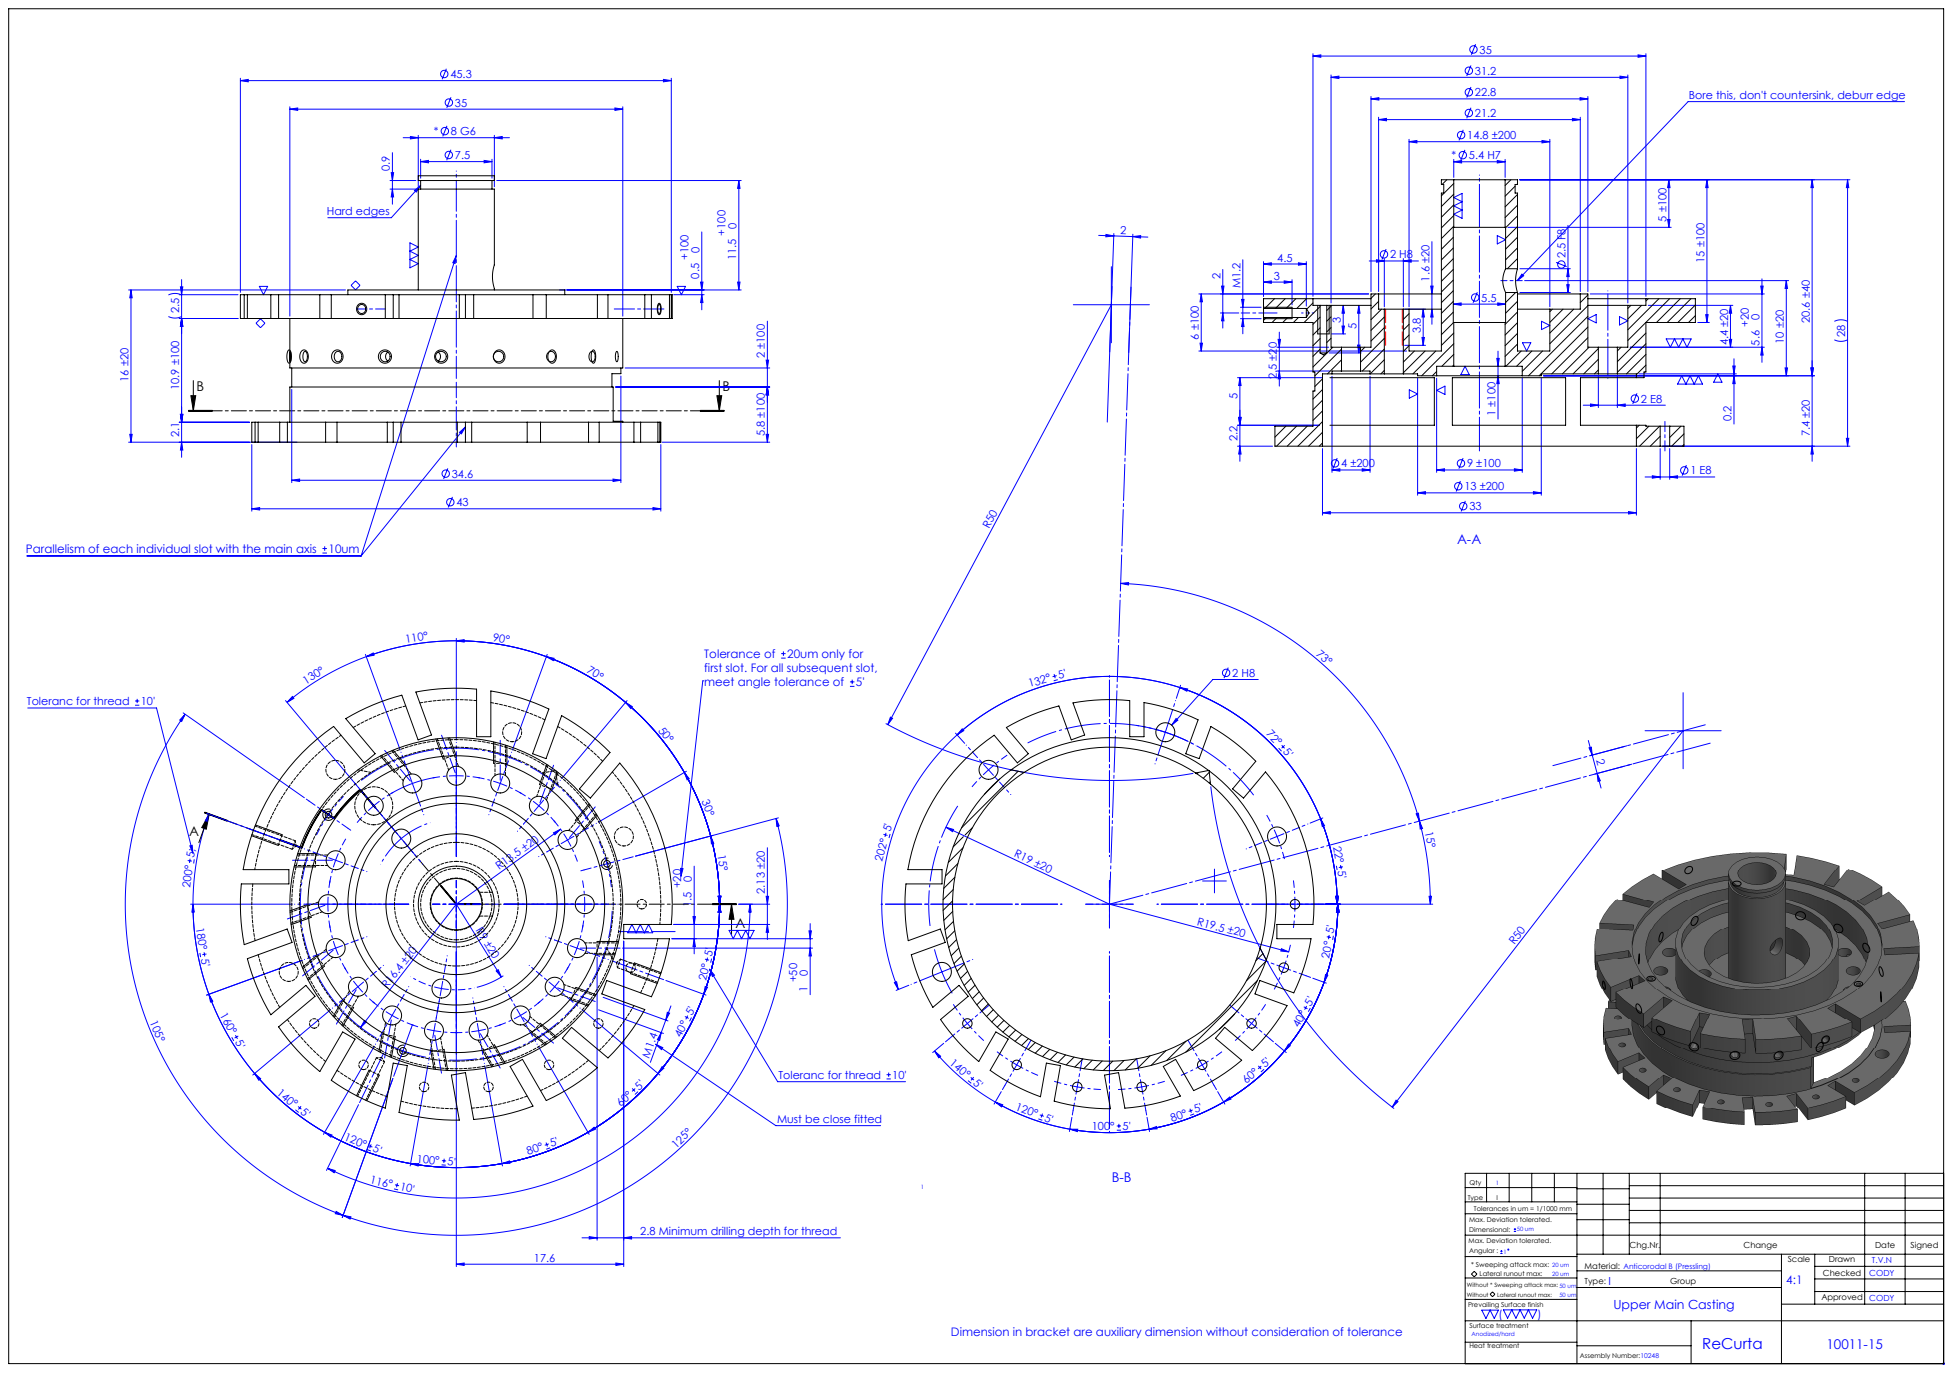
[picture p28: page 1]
Hard edges; Parallelism of each individual slot with the main axis; Toleranc for thread; Anticorodal B (Pressling); Tolerance of; 20um only for; meet angle tolerance of; Surface treatment; Heat treatment; Assembly Number:

Bore this, don't countersink, deburr edge

first slot. For all subsequent slot,

Must be close fitted

Qty | 1
Type | I

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

2.8 Minimum drilling depth for thread

Upper Main Casting

Dimension in bracket are auxiliary dimension without consideration of tolerance

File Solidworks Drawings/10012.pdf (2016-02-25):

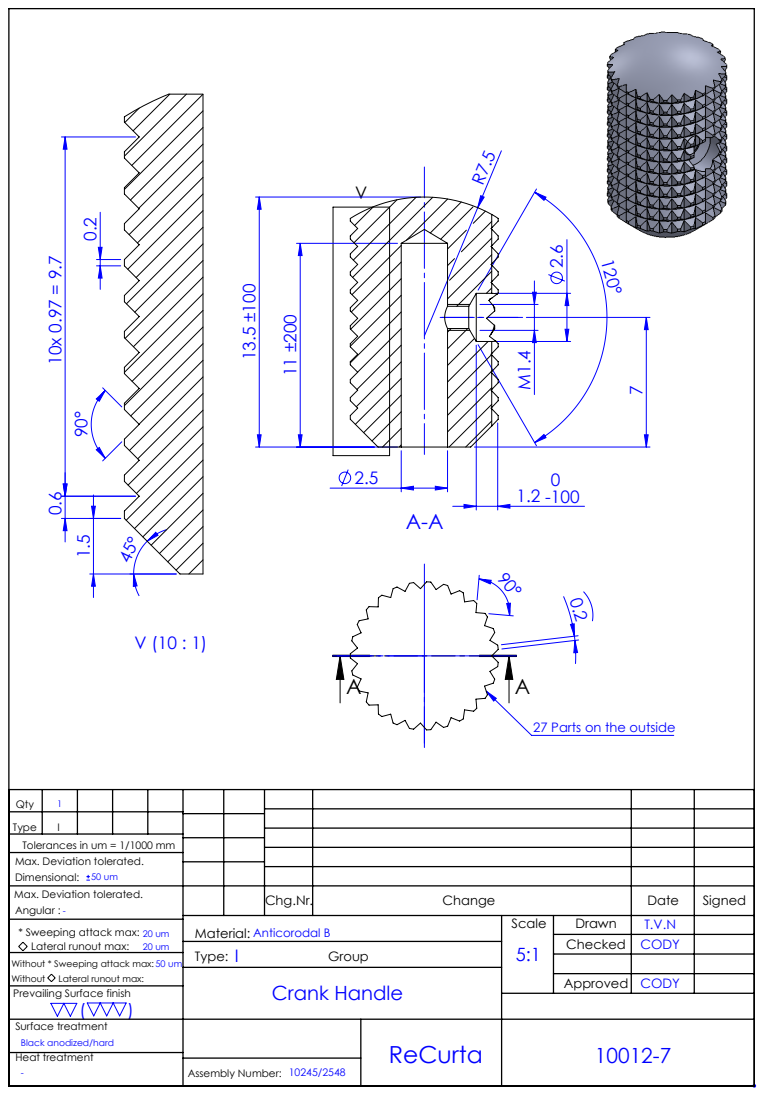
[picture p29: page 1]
Anticorodal B; Crank Handle; Scale; Drawn Material:; Assembly Number:

27 Parts on the outside

Qty | 1
Type | I

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

Surface treatment
Black anodized/hard
Heat treatment

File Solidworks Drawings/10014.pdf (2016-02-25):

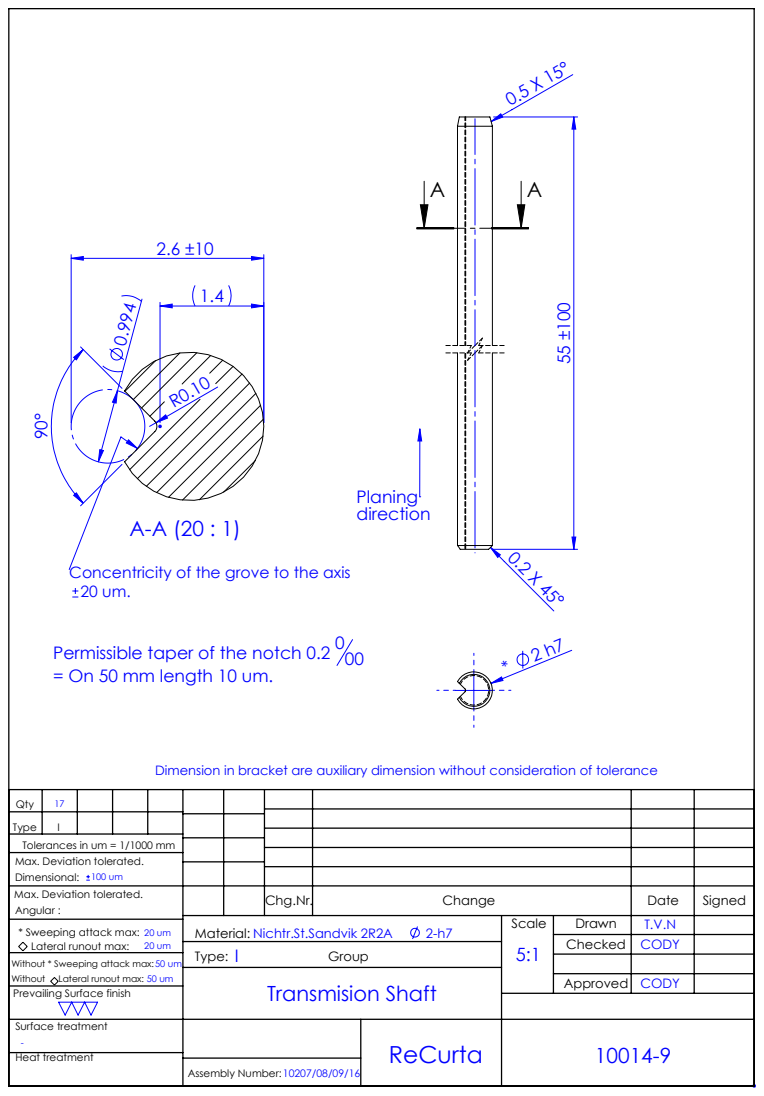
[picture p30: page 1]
Transmision Shaft; Assembly Number:; Heat treatment; Surface treatment

Concentricity of the grove to the axis

Permissible taper of the notch 0.2 0
= On 50 mm length 10 um.

Dimension in bracket are auxiliary dimension without consideration of tolerance

Qty | 17
Type | I

Tolerances in um = 1/1000 mm
Max. Deviation tolerated.
Dimensional:

Max. Deviation tolerated. Angular : | | | Chg.Nr. | Change | Date | Signed

Nichtr.St.Sandvik 2R2A 2-h7 | Scale 5:1 | Drawn Material: | T.V.N

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

Checked | CODY

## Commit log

2015-10-16 Added process field to BOM. Added initial Solidworks drawings.
    [10003-5.SLDPRT, 10004-3.SLDPRT, 10007-4.SLDDRW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]
2015-10-17 Added STL files.
    [10003.stl, 10004.stl, 10007.stl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]
2015-10-17 Added STL viewer to wiki builder.
2015-10-17 Cleaned up STL refs in wiki. Fixed offsets.
2015-10-17 Added more process details to BOM. Added part page region.
2015-10-17 Fixed more BOM entries.
2015-10-18 Swapped process for reversing plate. Added three new STLs.
    [10088-4a.stl, 10089-9.stl, 2074.stl]
2015-10-18 Fixed STL filenames.
    [10088.stl, 10089.stl]
2015-10-18 Updated 10089 stl.
    [10089.stl]
2015-10-20 Updated STL models.
    [10030.stl, 10034.stl, 10041.stl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]
2015-10-20 Added more new STLs
    [10001-12.stl, 10023-5.stl, 10047-5.stl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]
2015-10-20 Properly renamed STLs.
    [10001.stl, 10023.stl, 10047.stl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]
2015-10-20 Updated 10001's STL.
    [10001.stl]
2015-10-22 Updated to latest STLs.
    [10005.stl, 10006.stl, 10009.stl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]
2015-10-24 Added large backlog of new Solidworks Drawings.
    [10001-12.SLDPRT, 10005-9b.SLDPRT, 10006-10b.SLDPRT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]
2015-10-24 Added other new CMs and removed an unfinished Solidworks Drawing. Switched STL viewer to CM.
    [10058-1.SLDPRT]
2015-10-24 Improved materials a bit.
2015-10-27 Added backlog of Solidworks files. Updated STL viewer and model stuff.
    [10001-12.x_b, 10002-7.SLDPRT, 10003-5.SLDDRW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]
2016-02-25 Updated to latest solid works drawings.
    [10001-12.SLDDRW, 10001-12.SLDPRT, 10002-7.SLDDRW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]
2016-02-25 Renamed Solidworks files
    [10001.slddrw, 10001.sldprt, 10001.x_b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]
2016-02-25 Finished renaming.
    [10031-3.SLDPRT, 10031.SLDPRT, 10042-2.SLDPRT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]
2016-02-25 Fixed capitalization.
    [10066.slddrw, 10066.sldprt]
